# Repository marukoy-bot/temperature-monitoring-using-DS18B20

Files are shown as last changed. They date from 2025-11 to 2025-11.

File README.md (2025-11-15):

# Schematic
<div align="center">
    <image src="proj-temp-DS18B20_bb.png" height=350 alt="Circuit Diagram"/>
</div>

# Temperature Monitoring and Alarm System
Monitors temperature changes every 1 second and sends an SMS alert if certain temperature levels are reached. The buzzer module provides auditory alarm feedback while the RGY LED shows the current temperature level.
- if temperature < 50, light: green
- if temperature >= 50 && <= 70, light yellow, buzzer alarm, send SMS (5 mins. cooldown)
- if temperature > 70, light: red
- Sends SMS alerts if there is change in current temperature threshold level.
# GSM Subscription Feature
You can message the device certain keywords to perform subscription actions. Device can store up to 5 max contacts/subscribers. Subscribers = contacts/phone numbers.
- `GSM SUB` - subscribes to the device, will receive alert messages. It will also notify the user if they are already subscribed if tyring to subscribe again.
- `GSM UNSUB` - unsubscribers to the device, will no longer receive alerts messages.
- `GSM LIST` - gets the list of the subscribers.
- `GSM STATUS` - gets the current temperature, threshold level, and LED status. 
# Components
- DS18B20 temperature Sensor (probe)
- ESP32 + Breakout board
- SIM800L EVB GSM module
- Buzzer module
- RGY LED module
# Hardware Notes
- SIM800L (or GSM modules in general) consumes a lot of current when transmitting/receiving messages. This can be mitigated by
    - using a DC boost converter + >=1000uf capacitor in parallel to the power pins of the GSM Module. Capacitor must be placed as close to the GSM module as possible, with thick traces for lesser resistance. Boost converter should be set at least 4.4v, max 5v (depending on the GSM module model requirements).
    - using 2 USB power sources (1 plugged to ESP32, 1 plugged to breakout board to power GSM module + components) along with the boost converter + smoothing capacitors.

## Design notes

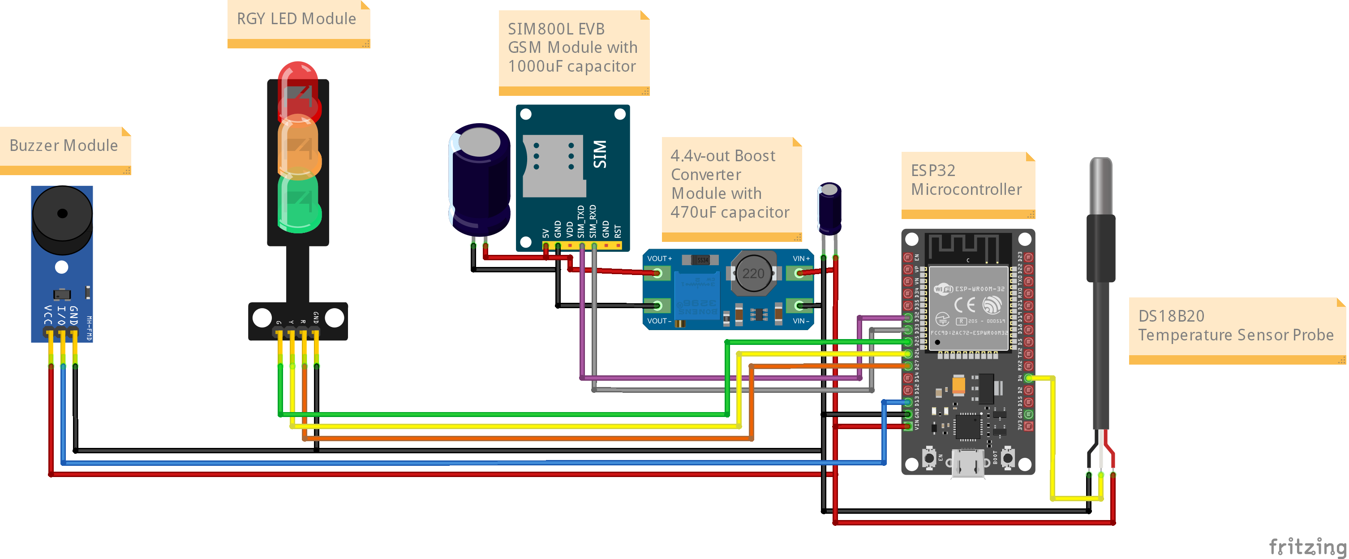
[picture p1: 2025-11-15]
proj-temp-DS18B20_bb.png

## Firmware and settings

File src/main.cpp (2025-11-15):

#include <Arduino.h>
#include <OneWire.h>
#include <DallasTemperature.h>
#include <SoftwareSerial.h>
#include <Preferences.h>

#define one_wire_bus    4 // A0
#define rx              32 // 2
#define tx              33 // 3
#define red             27   // 0
#define yellow          26   // 1
#define green           25   // 2
#define buzzer          13
#define MAX_SUBSCRIBERS 5

#define TEST false
#define test_num "+639xxxxxxxxx"

OneWire oneWire(one_wire_bus);
DallasTemperature temp_sensor(&oneWire);
SoftwareSerial gsm(rx, tx);

static const char* PREFS_NAMESPACE = "nums";
Preferences prefs;
String subscribers[MAX_SUBSCRIBERS];
int subscriber_count = 0;

float getTemperature();
void toggleLight(int color, bool state);
void toggleBuzzer(bool state);
void initializeGSM();
void updateGSM();
void onAlarm();
void offAlarm();
void sendSMS(String number, String message);
void getSubscriberList(String num);
void checkSMS();
void loadSubscribers();
void addSubscriber(String num);
void deleteSubscriber(String num);
bool isSubscribed(String num);
void clearNamespace();
void showStats();
void toggleLEDs();
void getStatus(String sender);

float temperature = 0;
unsigned long lastSMS = 0;
const unsigned long smsCooldown = 300000;   // 5 mins.
unsigned long last_loop_time = 0;
unsigned long lastCooldownPrint = 0;  // Track last cooldown print time
bool messageSent = false;
bool state_green = false, state_yellow = false, state_red = false, state_alarm = false, led_state = true;
int lastTempState = -1;  // Track last temperature state (-1: unknown, 0: cold, 1: moderate, 2: hot)
String tempLevel = "";

void setup() {
    Serial.begin(115200);
    temp_sensor.begin();    
    initializeGSM();
    loadSubscribers();
    pinMode(red, OUTPUT);
    pinMode(yellow, OUTPUT);
    pinMode(green, OUTPUT);
    pinMode(buzzer, OUTPUT);
    pinMode(2, OUTPUT);
    Serial.println("Components ready.");
}

void loop() {    
    checkSMS();

    if (millis() - last_loop_time >= 1000) {
        last_loop_time = millis();
        digitalWrite(2, led_state);
        led_state = !led_state;
        temperature = getTemperature();
        toggleLEDs();
        showStats();  
    }

    int currentTempState = -1;

    if (temperature < 50) {
        state_green = true;
        state_yellow = false;
        state_red = false;
        currentTempState = 0;
        tempLevel = "NORMAL";
    } 
    else if (temperature >= 50 && temperature <= 70) {
        state_green = false;
        state_yellow = true;
        state_red = false;
        currentTempState = 1;
        tempLevel = "MODERATE";
    }
    else if (temperature > 70) {
        state_green = false;
        state_yellow = false;
        state_red = true;
        currentTempState = 2;
        tempLevel = "HIGH";
    }

    // Check if temperature state has changed
    if (currentTempState != lastTempState) {
        lastTempState = currentTempState;
        messageSent = false;  // Reset message flag when state changes
        lastSMS = millis();   // Reset cooldown timer
    }

    // Send SMS alert based on current temperature state
    unsigned long elapsed = millis() - lastSMS;

    if (currentTempState == 0 && !messageSent) {
        // Moderate alert
        String message = "[ALERT]\nTemperature is NORMAL (" + String(temperature) + " C)"; 
        
        #if (TEST == false)
            for (int i = 0; i < subscriber_count; i++) {
                if (subscribers[i].length() > 0) {
                    sendSMS(subscribers[i], message);
                }
            }
        #else
            sendSMS(test_num, message);
        #endif
        
        Serial.println("NORMAL alert SMS sent to all subscribers.");
        messageSent = true;
    }
    else if (currentTempState == 1 && !messageSent) {
        // Moderate alert
        String message = "[ALERT]\nTemperature is MODERATE (" + String(temperature) + " C)";
        
        #if (TEST == false)
            for (int i = 0; i < subscriber_count; i++) {
                if (subscribers[i].length() > 0) {
                    sendSMS(subscribers[i], message);
                }
            }
        #else
            sendSMS(test_num, message);
        #endif
        
        Serial.println("Moderate alert SMS sent to all subscribers.");
        messageSent = true;
    }
    else if (currentTempState == 2 && !messageSent) {
        // Hot alert (high temperature)
        String message = "[WARNING]\nHIGH temperature detected (" + String(temperature) + " C)";
        
        #if (TEST == false)
            for (int i = 0; i < subscriber_count; i++) {
                if (subscribers[i].length() > 0) {
                    sendSMS(subscribers[i], message);
                }
            }
        #else
            sendSMS(test_num, message);
        #endif
        
        Serial.println("Hot alert SMS sent to all subscribers.");
        messageSent = true;
    }

    (currentTempState == 2) ? onAlarm() : offAlarm();
    
    if (elapsed < smsCooldown && messageSent) {
        if (millis() - lastCooldownPrint >= 1000) {
            lastCooldownPrint = millis();
            unsigned long remaining = (smsCooldown - elapsed) / 1000;
            Serial.println("SMS Cooldown: " + String(remaining) + " seconds");
        }
    }
}

float getTemperature() {
    temp_sensor.requestTemperatures();
    float temp_c = temp_sensor.getTempCByIndex(0);
    return temp_c != DEVICE_DISCONNECTED_C ? temp_c : 0;
}

void toggleLight(int color, bool state) {
    switch (color) {
        case 0: digitalWrite(red, state); break;
        case 1: digitalWrite(yellow, state); break;
        case 2: digitalWrite(green, state); break;
        default:
        {
            digitalWrite(red, LOW);
            digitalWrite(yellow, LOW);
            digitalWrite(green, LOW);
        }
    }
}

unsigned long lastToggle = 0;
bool buzzerState = false;
void onAlarm() {
    state_alarm = true;
    if (millis() - lastToggle >= 500) {
        lastToggle = millis();
        buzzerState = !buzzerState;
        toggleBuzzer(buzzerState);
    }
}

void offAlarm() {
    state_alarm = false;
    digitalWrite(buzzer, LOW);
}

void toggleBuzzer(bool state) {
    digitalWrite(buzzer, state);
}

void updateGSM() {
    delay(100);
    int timeout = 0;
    while (gsm.available() && timeout < 100) {
        Serial.write((char)gsm.read());
        timeout++;
        delay(5);
    }
}

void showStats() {
    Serial.println("temp: " + String(temperature) + "°C | G: " + String(state_green) + " | Y: " + String(state_yellow) + " | R: " + String(state_red) + " | Alarm: " + String(state_alarm ? "ON" : "OFF")); 
}

void toggleLEDs(){
    toggleLight(2, state_green);
    toggleLight(1, state_yellow);
    toggleLight(0, state_red);
}

void initializeGSM () {
    Serial.println("Checking module...");
    gsm.begin(9600);
    delay(100);

    gsm.println("AT");
    delay(100);

    gsm.println("AT+CSCS=\"GSM\"");
    delay(100);

    gsm.println("AT+CNMI=1,2,0,0,0");
    delay(100);

    gsm.println("AT+CMGF=1");
    delay(100);

    Serial.println("Updating time...");
    gsm.println("AT+CLTS=1");
    delay(100);

    gsm.println("AT&W");
    delay(100);
}

void sendSMS (String num, String message) {
    gsm.println("AT+CMGF=1");
    delay(100);
    
    gsm.println("AT+CMGS=\"" + num + "\"");
    delay(500);    

    gsm.print(message);
    gsm.print(char(26));
    delay(1000);
    updateGSM();
}

void loadSubscribers() {
    prefs.begin(PREFS_NAMESPACE, false);
    subscriber_count = prefs.getInt("count", 0);
    for (int i = 0; i < subscriber_count; i++) {
        String key = "num" + String(i);
        subscribers[i] = prefs.getString(key.c_str(), "");
        Serial.println(subscribers[i]);
    }
    prefs.end();  // Close after all operations
    Serial.println("Loaded " + String(subscriber_count) + " subscribers.");
}

void clearNamespace() {
    prefs.clear();
}

bool isSubscribed(String num) {
    for (int i = 0; i < subscriber_count; i++) {
        if (subscribers[i] == num) return true;
    }
    return false;
}

/// @brief add suscribers for sms feature
/// @param num mobile number of subscriber
void addSubscriber(String num) {
    if (isSubscribed(num)) {
        sendSMS(num, "[" + num + "] Already subscribed to device. Text GSM UNSUB to unsubscribe, GSM LIST to see list of subscribers. ");
        Serial.println("Already subscribed");
        return;
    }
    if (subscriber_count >= MAX_SUBSCRIBERS) {
        sendSMS(num, "Reached max. number of subscribers. Text GSM UNSUB to unsubscribe, GSM LIST to see list of subscribers. ");
        Serial.println("Reached max number of subscribers");
        return;
    }
    
    prefs.begin(PREFS_NAMESPACE, false);
    
    String key = "num" + String(subscriber_count);
    prefs.putString(key.c_str(), num);
    subscribers[subscriber_count] = num;
    subscriber_count++;
    prefs.putInt("count", subscriber_count);
    
    prefs.end();
    sendSMS(num, "[" + num + "] Subscribed to device. Text GSM UNSUB to unsubscribe, GSM LIST to see list of subscribers. ");
    Serial.println("Added subscriber: " + num);
}

void deleteSubscriber(String num) {
    bool found = false;

    for (int i = 0; i < subscriber_count; i++) {
        if (subscribers[i] == num) {
            for (int j = i; j < subscriber_count - 1; j++) {
                subscribers[j] = subscribers[j + 1];
            }
            subscriber_count--;
            found = true;
            break;
        }
    }

    if (found) {
        prefs.begin(PREFS_NAMESPACE, false);
        prefs.putInt("count", subscriber_count);

        for (int i = 0; i < subscriber_count; i++) {
            String key = "num" + String(i);
            prefs.putString(key.c_str(), subscribers[i]);
        }
        
        // Remove the last orphaned key
        String lastKey = "num" + String(subscriber_count);
        prefs.remove(lastKey.c_str());
        
        prefs.end();
        
        sendSMS(num, "[" + num + "] Unsubscribed to device. text GSM SUB to subscribe, GSM LIST to see list of subscribers.");
        Serial.println("Deleted subscriber: " + num);
    }
}

void checkSMS() {    
    if (gsm.available()) {
        String response = "";
        int timeout = 0;
        
        while (gsm.available() && timeout < 200) {
            response += (char)gsm.read();
            delay(5);
            timeout++;
        }

        response.toUpperCase();
        Serial.println(response);

        int numStartIndex = response.indexOf('"');
        int numEndIndex = response.indexOf('"', numStartIndex + 1);
        String sender = "", message = "";

        if (numStartIndex != -1 && numEndIndex != -1) {
            sender = response.substring(numStartIndex + 1, numEndIndex);
        }

        int msgStart = response.indexOf('\n', numEndIndex);
        if (msgStart != -1) {
            message = response.substring(msgStart + 1);
            message.trim();
        }

        if (message.indexOf("GSM SUB") > -1) {
            addSubscriber(sender);
        }
        else if (message.indexOf("GSM UNSUB") > -1) {
            deleteSubscriber(sender);
        }
        else if (message.indexOf("GSM LIST") > -1) {
            getSubscriberList(sender);
        }
        else if (message.indexOf("GSM STATUS") > -1) {
            getStatus(sender);
        }
    }    
}

void getSubscriberList(String sender) {
    String message = "";

    for (int i = 0; i < subscriber_count; i++) {
        message += String(i + 1) + ". " + subscribers[i] + "\n";
    }
    sendSMS(sender, message);
}

void getStatus(String sender) {
    String message = 
        "[STATUS]\nTemp: " + String(temperature) + " C\n"
        + "Level: " + tempLevel + "\n"
        + "LED: " + String(state_green ? "GREEN" : "") + String(state_yellow ? "YELLOW" : "") + String(state_red ? "RED" : "");

    sendSMS(sender, message);
}

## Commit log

2025-10-30 switched from arduino to ESP32, added subscription feature
2025-11-15 added fritzing schematic file and image
    [proj-temp-DS18B20.fzz]
2025-11-15 added test logic
    added alert on every threshold change
    fixed GSM delay and timeout
    added `GSM STATUS` feature
    [main.cpp]
